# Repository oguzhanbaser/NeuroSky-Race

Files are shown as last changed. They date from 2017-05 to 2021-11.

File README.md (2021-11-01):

# NeuroSky-Race

### If you want to use STM32F103 with this project, you should choose "stm32" branch. 

In this application you can use your attention level to control car speed. Application designed for two racers. You will need following items for this project:

    - NeuroSky Mindwave Sensors * 2
    - Arduino (Nano in this example but can be different) * 2
    - IRFZ44N Mosfet * 2
    - HC-05 Bluetooth * 2
    - Slot Car Track
    - MZ-80 (Optional) * 2
    - FTDI Converter(Optional) * 2
    - PC (Optional)

### First-Upload
For the first UPLOAD you have to uncomment this line in "configuration.h". Next time you can comment it again. This line saves speed levels to EEPROM. 

```arduino

//#define WRITE_EEPROM 

```

### Interface
If you want to use NodeJs web interface you will need a PC to run server. Connect two Arduino with USB cable to PC and set port names in "server.js"

```javascript
var portName1 = "COM5";         //if you use using Linux /dev/tty***
var portName2 = "COM13";        //if you are using Linux /dev/tty***
```

```sh

$ cd Web-Interface
$ npm install
$ node server.js

```

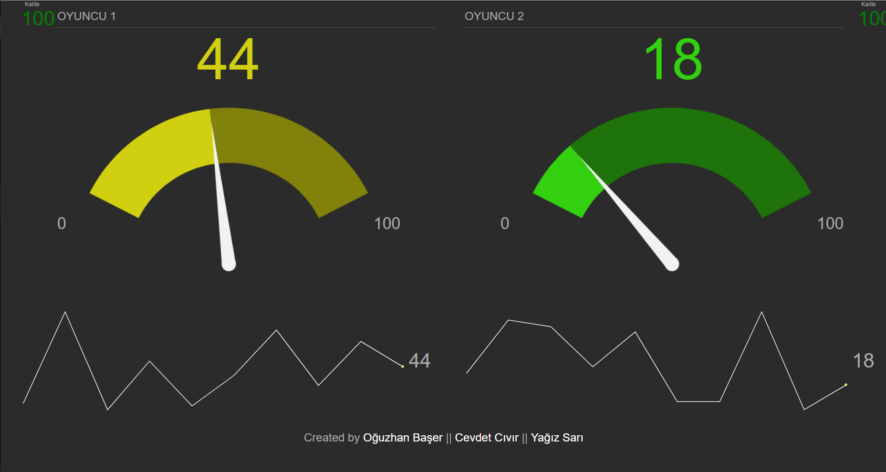
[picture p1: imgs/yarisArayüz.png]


### Software Serial
You can use FTDI converter or direct Arduino USB Plug to connect PC with Serial communication. You should uncomment this line in "configuration.h" and use A4 as RX, A5 as TX pin

```arduino

//#define USE_EXTERNAL_USB

```

## CARS WILL NOT MOVE IF .. !!
In this application if there are not two racers which are signal qualites equals zero(means max signal quality) cars cannot move. I needed this specification for race concept. If you want to disable it, comment this line in "configuration.h"

```arduino

#define MAKE_GAME

```

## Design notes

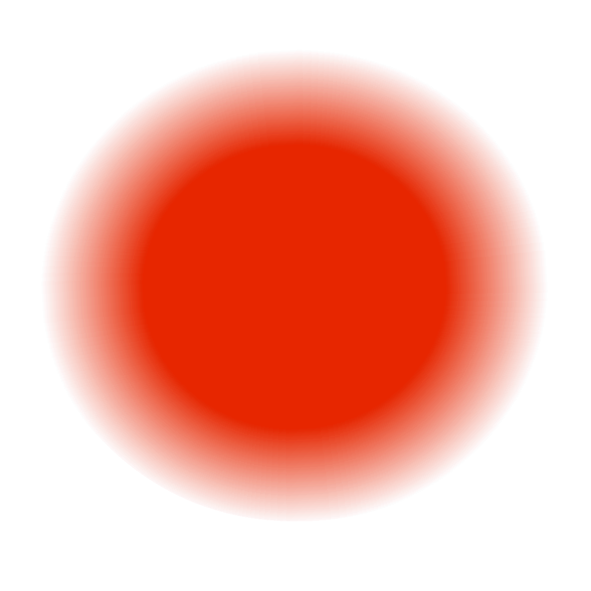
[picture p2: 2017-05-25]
Web-Interface/img/red.png

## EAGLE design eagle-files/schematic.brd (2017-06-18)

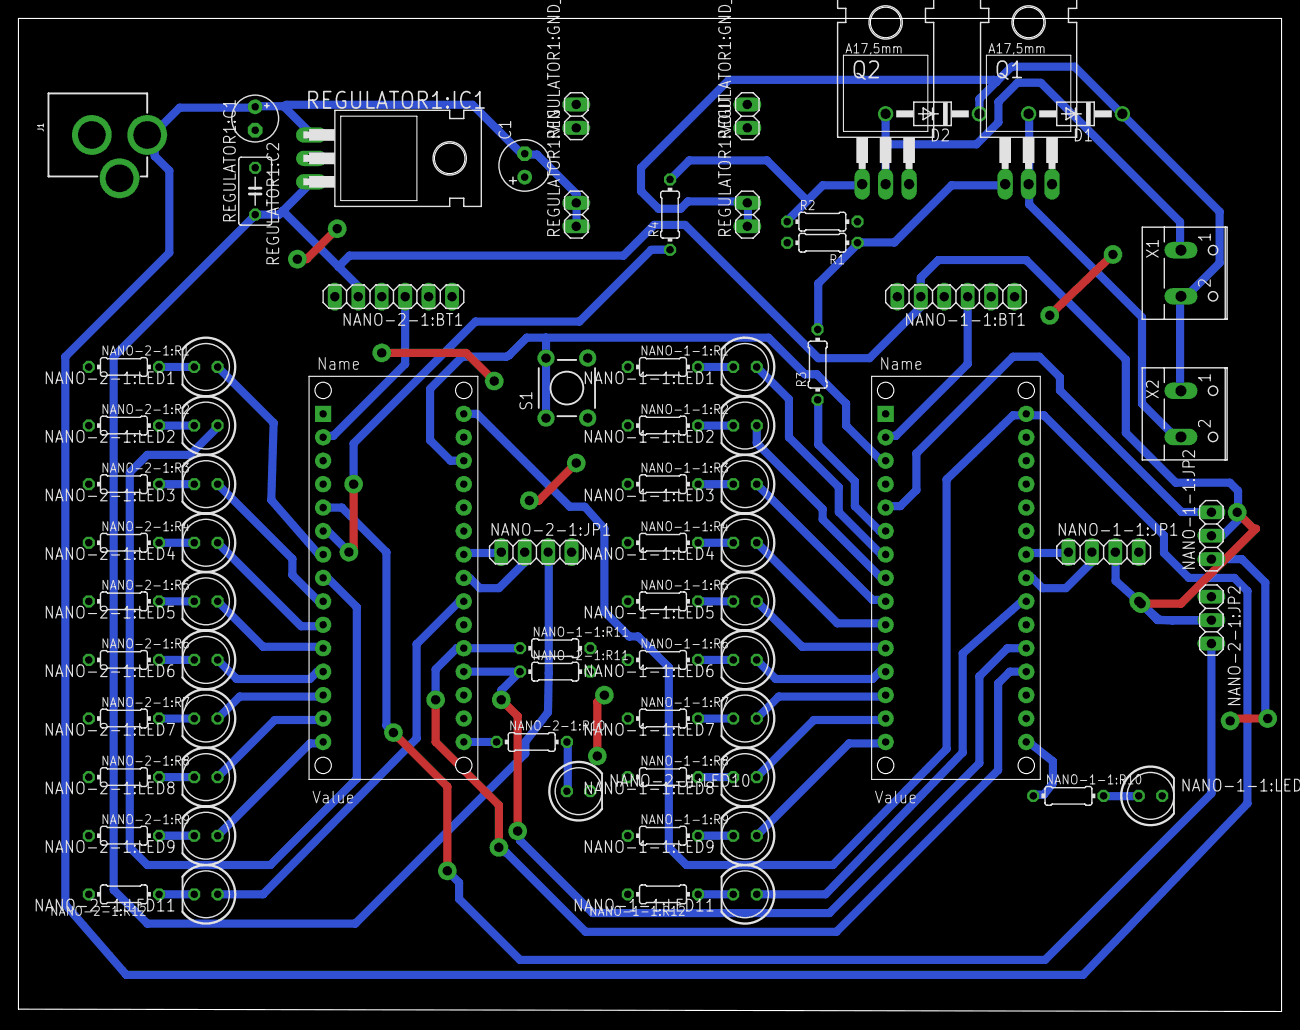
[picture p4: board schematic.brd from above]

Board: 2 copper layers, 136.9 x 107.6 mm, 74 parts (0 on the bottom side), 65 nets.

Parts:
C1: E2,5-6
D1, D2: 1N4004; DO41-10
J1: POWER_JACK; POWER_JACK_PTH
NANO-1-1:BT1, NANO-2-1:BT1: 1X06
NANO-1-1:JP1, NANO-2-1:JP1: 1X04
NANO-1-1:JP2, NANO-2-1:JP2: 1X03
NANO-1-1:LED1, NANO-1-1:LED2, NANO-1-1:LED3, NANO-1-1:LED4, NANO-1-1:LED5, NANO-1-1:LED6, NANO-1-1:LED7, NANO-1-1:LED8, NANO-1-1:LED9, NANO-1-1:LED10, NANO-1-1:LED11, NANO-2-1:LED1, NANO-2-1:LED2, NANO-2-1:LED3, NANO-2-1:LED4, NANO-2-1:LED5, NANO-2-1:LED6, NANO-2-1:LED7, NANO-2-1:LED8, NANO-2-1:LED9, NANO-2-1:LED10, NANO-2-1:LED11: LED5MM
NANO-1-1:R1, NANO-1-1:R2, NANO-1-1:R3, NANO-1-1:R4, NANO-1-1:R5, NANO-1-1:R6, NANO-1-1:R7, NANO-1-1:R8, NANO-1-1:R9, NANO-1-1:R10, NANO-1-1:R12, NANO-2-1:R2, NANO-2-1:R3, NANO-2-1:R4, NANO-2-1:R5, NANO-2-1:R6, NANO-2-1:R7, NANO-2-1:R8, NANO-2-1:R9: 0204/7
NANO-1-1:R11, NANO-2-1:R11: 10k; 0204/7
NANO-1-1:U$1, NANO-2-1:U$1: ARDUINONANO; PDIP-32
NANO-2-1:R1, NANO-2-1:R10, NANO-2-1:R12: 220; 0204/7
Q1, Q2: IRFZ48Z; TO220BH
R1, R2: 2.2k; 0204/7
R3, R4: 100; 0204/7
REGULATOR1:C1: C050-035X075
REGULATOR1:C2: E2,5-5
REGULATOR1:GND_IN, REGULATOR1:GND_OUT, REGULATOR1:VIN, REGULATOR1:VOUT: 1X02
REGULATOR1:IC1: 7805T; TO220H
S1: TACTILE-PTH
X1, X2: W237-102

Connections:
6V: D1.C, D2.C, REGULATOR1:VOUT.1, REGULATOR1:VOUT.2, X1.2, X2.1
GND: C1.+, J1.GND, J1.GNDBREAK, NANO-1-1:BT1.4, NANO-1-1:JP1.4, NANO-1-1:JP2.1, NANO-1-1:LED10.K, NANO-1-1:R1.1, NANO-1-1:R2.1, NANO-1-1:R3.1, NANO-1-1:R4.1, NANO-1-1:R5.1, NANO-1-1:R6.1, NANO-1-1:R7.1, NANO-1-1:R8.1, NANO-1-1:R9.1, NANO-1-1:R11.2, NANO-1-1:R12.2, NANO-1-1:U$1.GND, NANO-1-1:U$1.GND1, NANO-2-1:BT1.4, NANO-2-1:JP1.4, NANO-2-1:JP2.1, NANO-2-1:LED10.K, NANO-2-1:R1.1, NANO-2-1:R2.1, NANO-2-1:R3.1, NANO-2-1:R4.1, NANO-2-1:R5.1, NANO-2-1:R6.1, NANO-2-1:R7.1, NANO-2-1:R8.1, NANO-2-1:R9.1, NANO-2-1:R11.2, NANO-2-1:R12.2, NANO-2-1:U$1.GND, NANO-2-1:U$1.GND1, Q1.S, Q2.S, R1.2, R2.2, REGULATOR1:C1.2, REGULATOR1:C2.-, REGULATOR1:GND_IN.1, REGULATOR1:GND_IN.2, REGULATOR1:GND_OUT.1, REGULATOR1:GND_OUT.2, REGULATOR1:IC1.2, S1.3, S1.4
unnamed: Q1.G, R1.1, R3.2
unnamed: NANO-1-1:U$1.A6, NANO-2-1:R11.1, NANO-2-1:U$1.A7
unnamed: NANO-2-1:U$1.D3, R4.1
unnamed: NANO-1-1:R11.1, NANO-1-1:U$1.A7, NANO-2-1:U$1.A6
unnamed: D1.A, Q1.D, X2.2
unnamed: D2.A, Q2.D, X1.1
unnamed: NANO-1-1:U$1.D3, R3.1
unnamed: Q2.G, R2.1, R4.2
unnamed: NANO-1-1:U$1.RESET, NANO-2-1:U$1.RESET1, S1.1, S1.2
NANO-1-1:BT-TX: NANO-1-1:BT1.3, NANO-1-1:U$1.D0/RX
NANO-1-1:N$1: NANO-1-1:LED9.A, NANO-1-1:U$1.D12
NANO-1-1:N$2: NANO-1-1:LED8.A, NANO-1-1:U$1.D11
NANO-1-1:N$3: NANO-1-1:LED7.A, NANO-1-1:U$1.D10
NANO-1-1:N$4: NANO-1-1:LED6.A, NANO-1-1:U$1.D9
NANO-1-1:N$5: NANO-1-1:LED5.A, NANO-1-1:U$1.D8
NANO-1-1:N$6: NANO-1-1:LED4.A, NANO-1-1:U$1.D7
NANO-1-1:N$7: NANO-1-1:LED3.A, NANO-1-1:U$1.D6
NANO-1-1:N$8: NANO-1-1:LED2.A, NANO-1-1:U$1.D5
NANO-1-1:N$9: NANO-1-1:LED1.A, NANO-1-1:U$1.D4
NANO-1-1:N$10: NANO-1-1:R10.1, NANO-1-1:U$1.D13
NANO-1-1:N$11: NANO-1-1:LED1.K, NANO-1-1:R1.2
NANO-1-1:N$12: NANO-1-1:LED2.K, NANO-1-1:R2.2
NANO-1-1:N$13: NANO-1-1:LED3.K, NANO-1-1:R3.2
NANO-1-1:N$14: NANO-1-1:LED4.K, NANO-1-1:R4.2
NANO-1-1:N$15: NANO-1-1:LED5.K, NANO-1-1:R5.2
NANO-1-1:N$16: NANO-1-1:LED6.K, NANO-1-1:R6.2
NANO-1-1:N$17: NANO-1-1:LED7.K, NANO-1-1:R7.2
NANO-1-1:N$18: NANO-1-1:LED8.K, NANO-1-1:R8.2
NANO-1-1:N$19: NANO-1-1:LED9.K, NANO-1-1:R9.2
NANO-1-1:N$20: NANO-1-1:LED11.A, NANO-1-1:U$1.A4
NANO-1-1:N$21: NANO-1-1:LED11.K, NANO-1-1:R12.1
NANO-1-1:N$22: NANO-1-1:LED10.A, NANO-1-1:R10.2
NANO-1-1:N$23: NANO-1-1:JP1.1, NANO-1-1:U$1.A2
NANO-1-1:N$24: NANO-1-1:JP1.2, NANO-1-1:U$1.A3
NANO-1-1:N$25: NANO-1-1:JP2.3, NANO-1-1:U$1.D2
NANO-2-1:BT-TX: NANO-2-1:BT1.3, NANO-2-1:U$1.D0/RX
NANO-2-1:N$1: NANO-2-1:LED9.A, NANO-2-1:U$1.D12
NANO-2-1:N$2: NANO-2-1:LED8.A, NANO-2-1:U$1.D11
NANO-2-1:N$3: NANO-2-1:LED7.A, NANO-2-1:U$1.D10
NANO-2-1:N$4: NANO-2-1:LED6.A, NANO-2-1:U$1.D9
NANO-2-1:N$5: NANO-2-1:LED5.A, NANO-2-1:U$1.D8
NANO-2-1:N$6: NANO-2-1:LED4.A, NANO-2-1:U$1.D7
NANO-2-1:N$7: NANO-2-1:LED3.A, NANO-2-1:U$1.D6
NANO-2-1:N$8: NANO-2-1:LED2.A, NANO-2-1:U$1.D5
NANO-2-1:N$9: NANO-2-1:LED1.A, NANO-2-1:U$1.D4
NANO-2-1:N$10: NANO-2-1:LED11.K, NANO-2-1:R12.1
NANO-2-1:N$11: NANO-2-1:LED1.K, NANO-2-1:R1.2
NANO-2-1:N$12: NANO-2-1:LED2.K, NANO-2-1:R2.2
NANO-2-1:N$13: NANO-2-1:LED3.K, NANO-2-1:R3.2
NANO-2-1:N$14: NANO-2-1:LED4.K, NANO-2-1:R4.2
NANO-2-1:N$15: NANO-2-1:LED5.K, NANO-2-1:R5.2
NANO-2-1:N$16: NANO-2-1:LED6.K, NANO-2-1:R6.2
NANO-2-1:N$17: NANO-2-1:LED7.K, NANO-2-1:R7.2
NANO-2-1:N$18: NANO-2-1:LED8.K, NANO-2-1:R8.2
NANO-2-1:N$19: NANO-2-1:LED9.K, NANO-2-1:R9.2
NANO-2-1:N$20: NANO-2-1:LED11.A, NANO-2-1:U$1.A4
NANO-2-1:N$21: NANO-2-1:R10.1, NANO-2-1:U$1.D13
NANO-2-1:N$22: NANO-2-1:LED10.A, NANO-2-1:R10.2
NANO-2-1:N$23: NANO-2-1:JP1.1, NANO-2-1:U$1.A2
NANO-2-1:N$24: NANO-2-1:JP1.2, NANO-2-1:U$1.A3
NANO-2-1:N$25: NANO-2-1:JP2.3, NANO-2-1:U$1.D2
SENS_VOUT: NANO-1-1:BT1.5, NANO-1-1:JP1.3, NANO-1-1:JP2.2, NANO-2-1:BT1.5, NANO-2-1:JP1.3, NANO-2-1:JP2.2, REGULATOR1:C1.1, REGULATOR1:IC1.3
VIN: C1.-, J1.PWR, NANO-1-1:U$1.VIN, NANO-2-1:U$1.VIN, REGULATOR1:C2.+, REGULATOR1:IC1.1, REGULATOR1:VIN.1, REGULATOR1:VIN.2

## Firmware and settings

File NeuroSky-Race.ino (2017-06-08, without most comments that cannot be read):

////////////////////////////////////////////////////////////////////////
// Arduino Bluetooth Interface with Brainsense
//
// This is example code provided by Pantech Prolabs. and is provided
// license free.
////////////////////////////////////////////////////////////////////////
#include <Arduino.h>
#include <SoftwareSerial.h>
#include <EEPROM.h>
#include "configuration.h"

// checksum variables
byte generatedChecksum = 0;
byte checksum = 0;
int payloadLength = 0;
byte payloadData[64] = { 0 };
byte poorQuality = 200, lastPoorQuality = 200;
byte attention = 0, lastAttention = 0;
byte battery = 0;
byte meditation = 0;
int motorVal = 0;

// system variables
long lastReceivedPacket = 0;
boolean bigPacket = false;
bool ready = false, ready_in = false, stop_race = false;
unsigned long lastTime1 = 0, lastTime2 = 0;
int ledArray[LED_ARRAY_SIZE] = { GREENLED1, GREENLED2, GREENLED3, YELLOWLED1, YELLOWLED2,
YELLOWLED3, YELLOWLED4, REDLED1, REDLED2, REDLED3 };
uint8_t turSayisi = 0;

//software Serial
#ifdef USE_EXTERNAL_USB
SoftwareSerial usbSer(SOFT_SERIAL_RX, SOFT_SERIAL_TX);
#endif

//speed levels
uint8_t speedArray[ARRAY_SIZE];

#ifdef USE_MZ80
void tur_int()
{
	turSayisi++;

	//if lap count equals to ten stop the race
	if (turSayisi > 10)
	{
		stop_race = true;
		ready = false;
	}
}
#endif

//////////////////////////
// Microprocessor Setup //
//////////////////////////
void setup()
{
#ifdef USE_EXTERNAL_USB
	usbSer.begin(DEBUG_BAUDRATE);
#endif
	Serial.begin(BAUDRATE);           // USB

	//need for proteus simulation runnig 
#ifdef MAKE_SIM
	setSpeedArray();
#endif

	//need for first uploading
#ifdef WRITE_EEPROM
	setSpeedArray();

	for (int i = 0; i < ARRAY_SIZE; i++)
	{
		EEPROM.write(i, speedArray[i]);
	}
#endif

	//need for reading eeprom values
#ifdef DEBUG_EEPROM
	for (int i = 0; i < ARRAY_SIZE; i++)
	{
		speedArray[i] = EEPROM.read(i);
		Serial.print("Val: ");
		Serial.print(i);
		Serial.print(" ");
		Serial.println(speedArray[i]);
	}
#endif

	//speed val initialize
	for (int i = 0; i < ARRAY_SIZE; i++)
	{
		speedArray[i] = EEPROM.read(i);
	}

	//attention leve indicators
	pinMode(GREENLED1, OUTPUT);
	pinMode(GREENLED2, OUTPUT);
	pinMode(GREENLED3, OUTPUT);
	pinMode(YELLOWLED1, OUTPUT);
	pinMode(YELLOWLED2, OUTPUT);
	pinMode(YELLOWLED3, OUTPUT);
	pinMode(YELLOWLED4, OUTPUT);
	pinMode(REDLED1, OUTPUT);
	pinMode(REDLED2, OUTPUT);
	pinMode(REDLED3, OUTPUT);
	pinMode(MOTOR_OUT, OUTPUT);

	//Players ready?
	pinMode(READY_IN, INPUT);
	pinMode(READY_OUT, OUTPUT);

#ifdef USE_MZ80
	attachInterrupt(digitalPinToInterrupt(MZ_80), tur_int, FALLING);
#endif

	//poor quality indicator led
	pinMode(LED, OUTPUT);
}

////////////////////////////////
// Read data from Serial UART //
////////////////////////////////
byte ReadOneByte()

{
	int ByteRead;
	while (!Serial.available());
	lastTime2 = millis();
	ByteRead = Serial.read();

#if DEBUGOUTPUT
	Serial.print((char)ByteRead);   // echo the same byte out the USB serial (for debug purposes)
#endif

	return ByteRead;
}

/////////////
//MAIN LOOP//
/////////////
void loop()
{

#ifndef MAKE_GAME
	ready = true;
	ready_in = true;
#else
	ready_in = digitalRead(READY_IN);
#endif

	digitalWrite(READY_OUT, ready);


	if (millis() - lastTime2 > TIMEOUT)
	{
		lastPoorQuality = 200;
		lastAttention = 0;
		lastTime2 = millis();
#ifdef USE_EXTERNAL_USB
		Serial.println("Timeout reached");
#endif
		for (int i = 0; i < LED_ARRAY_SIZE; i++)
		{
			digitalWrite(ledArray[i], LOW);
		}
	}

	//If the race end stop the cars
#ifdef MAKE_GAME
	if (stop_race)
	{
		analogWrite(MOTOR_OUT, 0);
	}
#endif

	/*
	if (usbSer.available())
	{
		char c = usbSer.read();

		int index = 'a' - c;

		int val = usbSer.parseInt();

		if ((index <= 10) && (index >= 0 ) && 
			(val <= 255) && (val >= 0))
		{
			speedArray[index] = val;
			EEPROM.write(index, speedArray[index]);
		}
	}*/

	if (Serial.available())

	{
		// Look for sync bytes
		if (ReadOneByte() == 170)
		{
			if (ReadOneByte() == 170)
			{
				payloadLength = ReadOneByte();

				if (payloadLength > 169)                     //Payload length can not be greater than 169
					return;
				generatedChecksum = 0;
				for (int i = 0; i < payloadLength; i++)
				{
					payloadData[i] = ReadOneByte();            //Read payload into memory
					generatedChecksum += payloadData[i];
				}

				checksum = ReadOneByte();                      //Read checksum byte from stream
				generatedChecksum = 255 - generatedChecksum;   //Take one's compliment of generated checksum


				if (checksum == generatedChecksum)
				{
					poorQuality = 200;
					attention = 0;
					meditation = 0;
					lastTime2 = millis();

					for (int i = 0; i < payloadLength; i++)
					{ // Parse the payload
						switch (payloadData[i])
						{
						case 2:
							i++;
							poorQuality = payloadData[i];
							lastPoorQuality = poorQuality;
							bigPacket = true;
							break;
						case 3:
							i++;
							battery = payloadData[i];
							break;
						case 4:
							i++;
							attention = payloadData[i];
							lastAttention = attention;
							break;
						case 5:
							i++;
							meditation = payloadData[i];
							break;
						case 0x80:
							i = i + 3;
							break;
						case 0x83:
							i = i + 25;
							break;
						default:
							break;
						} // switch
					} // for loop

#if !DEBUGOUTPUT

					if (bigPacket)
					{
						if (poorQuality == 0)
						{
							digitalWrite(LED, HIGH);
							ready = true;
						}
						else
						{
							attention = 0;
							digitalWrite(LED, LOW);
							ready = false;
						}	

#ifdef USE_EXTERNAL_USB
						Serial.print("Signal Quality: ");
						Serial.print(poorQuality, DEC);
						Serial.print(" Meditation: ");
						Serial.print(meditation, DEC);
						Serial.print(" Attention: ");
						Serial.print(attention, DEC);
						Serial.print(" Time since last packet: ");
						Serial.print(millis() - lastReceivedPacket, DEC);
						lastReceivedPacket = millis();
						Serial.println();
#endif

						switch (attention / 10)
						{
						case 0:
							digitalWrite(GREENLED1, HIGH);
							digitalWrite(GREENLED2, LOW);
							digitalWrite(GREENLED3, LOW);
							digitalWrite(YELLOWLED1, LOW);
							digitalWrite(YELLOWLED2, LOW);
							digitalWrite(YELLOWLED3, LOW);
							digitalWrite(YELLOWLED4, LOW);
							digitalWrite(REDLED1, LOW);
							digitalWrite(REDLED2, LOW);
							digitalWrite(REDLED3, LOW);
							motorVal = speedArray[0];
							break;
						case 1:
							digitalWrite(GREENLED1, HIGH);
							digitalWrite(GREENLED2, HIGH);
							digitalWrite(GREENLED3, LOW);
							digitalWrite(YELLOWLED1, LOW);
							digitalWrite(YELLOWLED2, LOW);
							digitalWrite(YELLOWLED3, LOW);
							digitalWrite(YELLOWLED4, LOW);
							digitalWrite(REDLED1, LOW);
							digitalWrite(REDLED2, LOW);
							digitalWrite(REDLED3, LOW);
							motorVal = speedArray[1];
							break;
						case 2:
							digitalWrite(GREENLED1, HIGH);
							digitalWrite(GREENLED2, HIGH);
							digitalWrite(GREENLED3, HIGH);
							digitalWrite(YELLOWLED1, LOW);
							digitalWrite(YELLOWLED2, LOW);
							digitalWrite(YELLOWLED3, LOW);
							digitalWrite(YELLOWLED4, LOW);
							digitalWrite(REDLED1, LOW);
							digitalWrite(REDLED2, LOW);
							digitalWrite(REDLED3, LOW);
							motorVal = speedArray[2];
							break;
						case 3:
							digitalWrite(GREENLED1, HIGH);
							digitalWrite(GREENLED2, HIGH);
							digitalWrite(GREENLED3, HIGH);
							digitalWrite(YELLOWLED1, HIGH);
							digitalWrite(YELLOWLED2, LOW);
							digitalWrite(YELLOWLED3, LOW);
							digitalWrite(YELLOWLED4, LOW);
							digitalWrite(REDLED1, LOW);
							digitalWrite(REDLED2, LOW);
							digitalWrite(REDLED3, LOW);
							motorVal = speedArray[3];
							break;
						case 4:
							digitalWrite(GREENLED1, HIGH);
							digitalWrite(GREENLED2, HIGH);
							digitalWrite(GREENLED3, HIGH);
							digitalWrite(YELLOWLED1, HIGH);
							digitalWrite(YELLOWLED2, HIGH);
							digitalWrite(YELLOWLED3, LOW);
							digitalWrite(YELLOWLED4, LOW);
							digitalWrite(REDLED1, LOW);
							digitalWrite(REDLED2, LOW);
							digitalWrite(REDLED3, LOW);
							motorVal = speedArray[4];
							break;
						case 5:
							digitalWrite(GREENLED1, HIGH);
							digitalWrite(GREENLED2, HIGH);
							digitalWrite(GREENLED3, HIGH);
							digitalWrite(YELLOWLED1, HIGH);
							digitalWrite(YELLOWLED2, HIGH);
							digitalWrite(YELLOWLED3, HIGH);
							digitalWrite(YELLOWLED4, LOW);
							digitalWrite(REDLED1, LOW);
							digitalWrite(REDLED2, LOW);
							digitalWrite(REDLED3, LOW);
							motorVal = speedArray[5];
							break;
						case 6:
							digitalWrite(GREENLED1, HIGH);
							digitalWrite(GREENLED2, HIGH);
							digitalWrite(GREENLED3, HIGH);
							digitalWrite(YELLOWLED1, HIGH);
							digitalWrite(YELLOWLED2, HIGH);
							digitalWrite(YELLOWLED3, HIGH);
							digitalWrite(YELLOWLED4, HIGH);
							digitalWrite(REDLED1, LOW);
							digitalWrite(REDLED2, LOW);
							digitalWrite(REDLED3, LOW);
							motorVal = speedArray[6];
							break;
						case 7:
							digitalWrite(GREENLED1, HIGH);
							digitalWrite(GREENLED2, HIGH);
							digitalWrite(GREENLED3, HIGH);
							digitalWrite(YELLOWLED1, HIGH);
							digitalWrite(YELLOWLED2, HIGH);
							digitalWrite(YELLOWLED3, HIGH);
							digitalWrite(YELLOWLED4, HIGH);
							digitalWrite(REDLED1, HIGH);
							digitalWrite(REDLED2, LOW);
							digitalWrite(REDLED3, LOW);
							motorVal = speedArray[7];
							break;
						case 8:
							digitalWrite(GREENLED1, HIGH);
							digitalWrite(GREENLED2, HIGH);
							digitalWrite(GREENLED3, HIGH);
							digitalWrite(YELLOWLED1, HIGH);
							digitalWrite(YELLOWLED2, HIGH);
							digitalWrite(YELLOWLED3, HIGH);
							digitalWrite(YELLOWLED4, HIGH);
							digitalWrite(REDLED1, HIGH);
							digitalWrite(REDLED2, HIGH);
							digitalWrite(REDLED3, LOW);
							motorVal = speedArray[8];
							break;
						case 9:
							digitalWrite(GREENLED1, HIGH);
							digitalWrite(GREENLED2, HIGH);
							digitalWrite(GREENLED3, HIGH);
							digitalWrite(YELLOWLED1, HIGH);
							digitalWrite(YELLOWLED2, HIGH);
							digitalWrite(YELLOWLED3, HIGH);
							digitalWrite(YELLOWLED4, HIGH);
							digitalWrite(REDLED1, HIGH);
							digitalWrite(REDLED2, HIGH);
							digitalWrite(REDLED3, HIGH);
							motorVal = speedArray[9];
							break;
						case 10:
							digitalWrite(GREENLED1, HIGH);
							digitalWrite(GREENLED2, HIGH);
							digitalWrite(GREENLED3, HIGH);
							digitalWrite(YELLOWLED1, HIGH);
							digitalWrite(YELLOWLED2, HIGH);
							digitalWrite(YELLOWLED3, HIGH);
							digitalWrite(YELLOWLED4, HIGH);
							digitalWrite(REDLED1, HIGH);
							digitalWrite(REDLED2, HIGH);
							digitalWrite(REDLED3, HIGH);
							motorVal = speedArray[10];
							break;
						}

						if (ready && ready_in)
						{
							motorVal = motorVal;
						}
						else{
							//analogWrite(MOTOR_OUT, 0);
							for (int i = 0; i < ARRAY_SIZE; i++)
							{
								digitalWrite(ledArray[i], LOW);
							}
							motorVal = 0;
						}
					}
#endif
					bigPacket = false;
				}
				else {
					// Checksum Error
				}  // end if else for checksum
			} // end if read 0xAA byte
		} // end if read 0xAA byte
	}

	//send siqnal quality and attention level per second
	if (millis() - lastTime1 > INTERVAL)
	{
		String ss = "#|" + String(lastPoorQuality) + "|" + String(lastAttention);
#ifdef USE_EXTERNAL_USB
		usbSer.println(ss);
#endif

#ifndef USE_EXTERNAL_USB
		Serial.println(ss);
#endif
		lastTime1 = millis();
	}

	analogWrite(MOTOR_OUT, motorVal);
}

//default speed array
void setSpeedArray()
{
	speedArray[0] = 0;
	speedArray[1] = 0;
	speedArray[2] = 0;
	speedArray[3] = 0;
	speedArray[4] = 90;
	speedArray[5] = 95;
	speedArray[6] = 100;
	speedArray[7] = 105;
	speedArray[8] = 110;
	speedArray[9] = 120;
	speedArray[10] = 130;
}

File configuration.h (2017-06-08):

//#define WRITE_EEPROM 
#define DEBUG_EEPROM
//#define USE_EXTERNAL_USB
//#define MAKE_SIM
#define MAKE_GAME               //uncomment it if you are make test

#ifdef MAKE_GAME
#define USE_MZ80
#endif

#define LED 13                  //siqnal quality indicator led
#define BAUDRATE 57600          //do not change this. This baud rate NeuroSky' s baud rate
#define DEBUGOUTPUT 0
#ifdef USE_EXTERNAL_USB
#define DEBUG_BAUDRATE 9600
#endif

//attention level indicator led pins
#define GREENLED1  4
#define GREENLED2  5
#define GREENLED3  6
#define YELLOWLED1 7
#define YELLOWLED2 8
#define YELLOWLED3 9
#define YELLOWLED4 10
#define REDLED1    11
#define REDLED2    12
#define REDLED3    A3

/*
    Ready In and Ready Out requires to check are the players connected?
    If this player' s poor quality equals to 0, Ready out will set high
    If the other player' s poor quality equals to 0, its arduino will set own ready out pin to high
    So we can check is the other player connected
*/
#define READY_IN   A1
#define READY_OUT  A0

//Software Serial pins
#define SOFT_SERIAL_RX A4
#define SOFT_SERIAL_TX A5

#define MOTOR_OUT 3         //mosfet gate pin

#define ARRAY_SIZE 11

#define MZ_80	2

#define INTERVAL 500
#define TIMEOUT	3000

#define LED_ARRAY_SIZE 10

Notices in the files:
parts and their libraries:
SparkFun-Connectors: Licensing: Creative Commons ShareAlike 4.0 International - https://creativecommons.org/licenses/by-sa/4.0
